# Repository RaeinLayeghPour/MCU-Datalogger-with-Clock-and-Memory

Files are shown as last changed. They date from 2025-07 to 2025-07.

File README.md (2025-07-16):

# MCU Datalogger with Clock and Memory

A microcontroller-based data logging system featuring a real-time clock (RTC) and external memory (EEPROM/SPI flash) to timestamp and store sensor readings for offline retrieval and analysis.

---

## Features

- Real-time timestamping via DS3231 (I²C RTC module)
- Data storage on external EEPROM or SPI flash memory
- Configurable sampling interval and data format
- Power-efficient design for long-term deployment
- Accessible serial interface for data download/monitoring

---

## Tech Stack & Hardware

- **MCU:** Arduino Uno / ATmega328P
- **RTC:** DS3231 module (I²C)
- **Memory:** External EEPROM or SPI flash (e.g., 24LC256, 25LC512)
- **Language:** Arduino C/C++
- **Interface:** Serial (USB) + I²C/SPI protocols

---

## How It Works

1. On boot, the MCU initializes the RTC and memory.
2. Sensor data (analog/digital) is sampled at configured intervals.
3. Each reading is timestamped using the RTC.
4. Records are stored sequentially in external memory.
5. Data can be retrieved via serial commands (e.g., `dump`, `clear`).

---

## Applications

- Remote environmental monitoring (e.g., temperature, humidity)
- Power data logging (voltage/current)
- Industrial sensing (vibration, pressure)
- Educational electronics and embedded systems projects

---

## 📬 Contact

Reach out if you’d like to collaborate or discuss enhancements:

- [LinkedIn](https://www.linkedin.com/in/raeinlp)
- Email: raeen.layegh2017@gmail.com

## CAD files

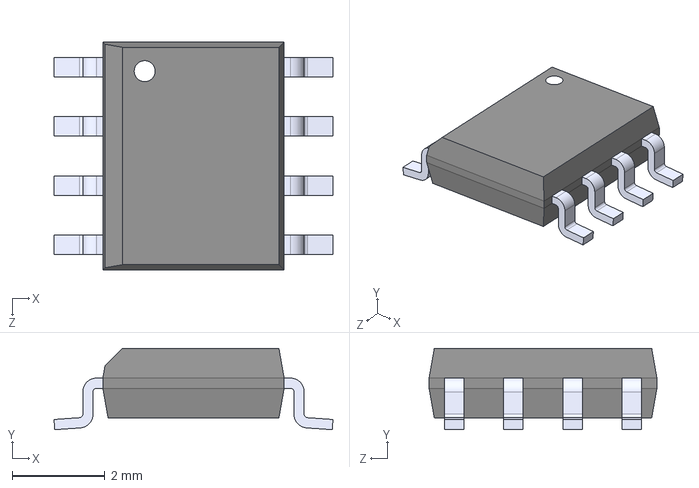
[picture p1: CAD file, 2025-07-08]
DS1337S+.STEP
6.00 x 1.75 x 4.90 mm

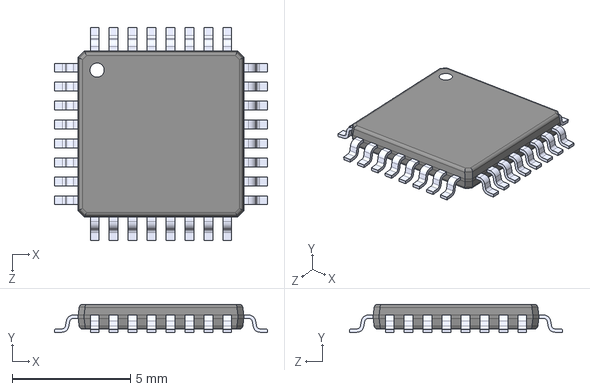
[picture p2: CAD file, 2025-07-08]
ATMEGA328P-AUR.step
9.00 x 1.20 x 9.00 mm

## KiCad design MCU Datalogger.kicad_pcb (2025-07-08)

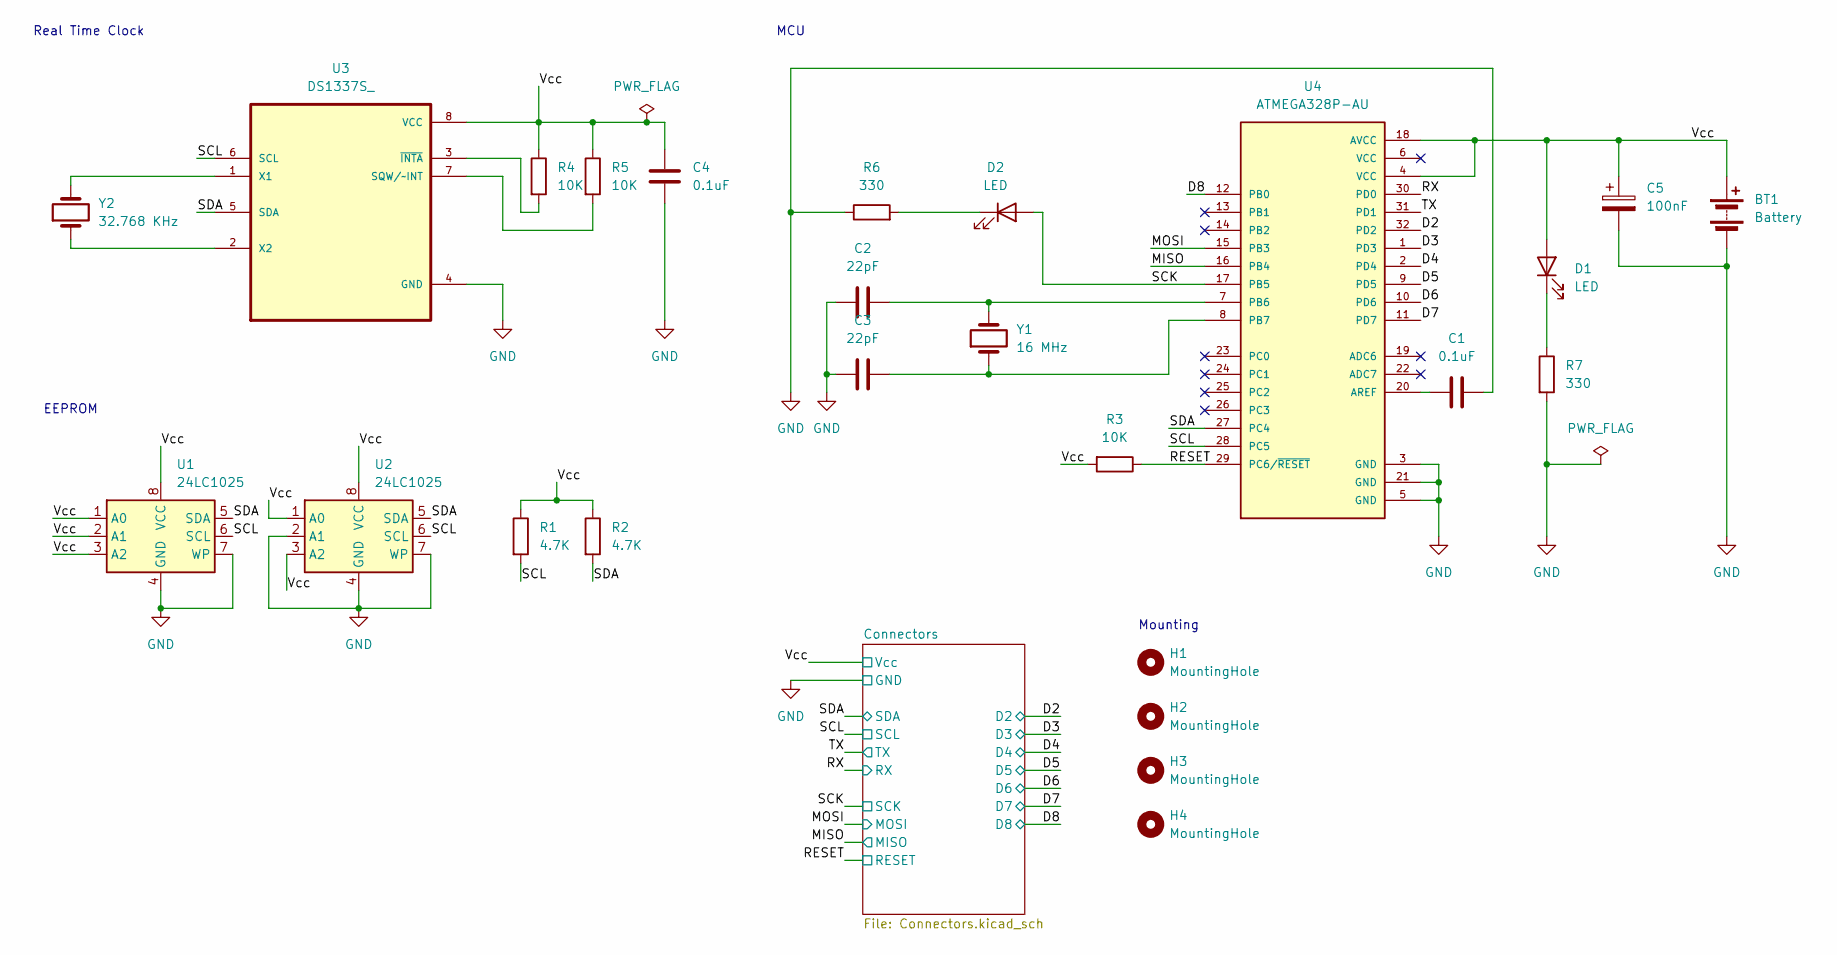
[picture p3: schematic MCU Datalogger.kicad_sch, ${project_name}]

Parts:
BT1: Battery; PinHeader_1x02_P2.54mm_Vertical
C1, C4: 0.1uF; C_0805_2012Metric
C2, C3: 22pF; C_0805_2012Metric
C5: 100nF; C_0805_2012Metric
D1, D2: LED; LED_0805_2012Metric
H1, H2, H3, H4: MountingHole; MountingHole_2.1mm
R1, R2: 4.7K; R_0805_2012Metric
R3, R4, R5: 10K; R_0805_2012Metric
R6, R7: 330; R_0805_2012Metric
U1, U2: 24LC1025; SSOP-8_5.25x5.24mm_P1.27mm
U3: DS1337S_; SOIC127P600X175-8N
U4: ATMEGA328P-AU; QFP80P900X900X120-32N; PARTREV 8271A
Y1: 16 MHz; Crystal_SMD_5032-2Pin_5.0x3.2mm_HandSoldering
Y2: 32.768 KHz; Crystal_SMD_5032-2Pin_5.0x3.2mm_HandSoldering

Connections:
/D2: U4.32 (PD2); also elsewhere on the board
/D3: U4.1 (PD3); also elsewhere on the board
/D4: U4.2 (PD4); also elsewhere on the board
/D5: U4.9 (PD5); also elsewhere on the board
/D6: U4.10 (PD6); also elsewhere on the board
/D7: U4.11 (PD7); also elsewhere on the board
/D8: U4.12 (PB0); also elsewhere on the board
/MISO: U4.16 (PB4); also elsewhere on the board
/MOSI: U4.15 (PB3); also elsewhere on the board
/RESET: R3.1, U4.29 (PC6/~RESET); also elsewhere on the board
/RX: U4.30 (PD0); also elsewhere on the board
/SCK: D2.2 (A), U4.17 (PB5); also elsewhere on the board
/SCL: R1.2, U1.6 (SCL), U2.6 (SCL), U3.6 (SCL), U4.28 (PC5); also elsewhere on the board
/SDA: R2.2, U1.5 (SDA), U2.5 (SDA), U3.5 (SDA), U4.27 (PC4); also elsewhere on the board
/TX: U4.31 (PD1); also elsewhere on the board
/Vcc: BT1.1 (+), C4.1, C5.1, D1.2 (A), R1.1, R2.1, R3.2, R4.1, R5.1, U1.1 (A0), U1.2 (A1), U1.3 (A2), U1.8 (VCC), U2.1 (A0), U2.3 (A2), U2.8 (VCC), U3.8 (VCC), U4.4 (VCC), U4.18 (AVCC); also elsewhere on the board
GND: BT1.2 (-), C1.2, C2.1, C3.1, C4.2, C5.2, R6.1, R7.2, U1.4 (GND), U1.7 (WP), U2.2 (A1), U2.4 (GND), U2.7 (WP), U3.4 (GND), U4.3 (GND), U4.5 (GND), U4.21 (GND); also elsewhere on the board
unnamed: D1.1 (K), R7.1
unnamed: D2.1 (K), R6.2
unnamed: R5.2, U3.7 (SQW/~INT)
unnamed: U3.1 (X1), Y2.2
unnamed: U3.2 (X2), Y2.1
unnamed: R4.2, U3.3 (~INTA)
unnamed: C1.1, U4.20 (AREF)
unnamed: C2.2, U4.7 (PB6), Y1.2
unnamed: C3.2, U4.8 (PB7), Y1.1

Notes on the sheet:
EEPROM
Mounting
MCU
Real Time Clock

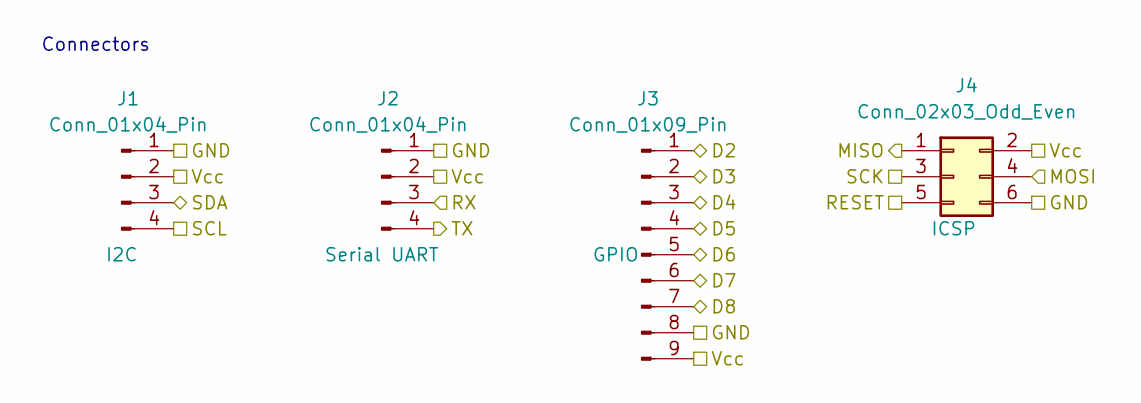
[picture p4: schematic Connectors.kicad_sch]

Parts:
J1, J2: Conn_01x04_Pin; PinHeader_1x04_P2.54mm_Vertical
J3: Conn_01x09_Pin; PinHeader_1x09_P2.54mm_Vertical
J4: Conn_02x03_Odd_Even; PinHeader_2x03_P2.54mm_Vertical

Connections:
/D2: J3.1; also elsewhere on the board
/D3: J3.2; also elsewhere on the board
/D4: J3.3; also elsewhere on the board
/D5: J3.4; also elsewhere on the board
/D6: J3.5; also elsewhere on the board
/D7: J3.6; also elsewhere on the board
/D8: J3.7; also elsewhere on the board
/MISO: J4.1; also elsewhere on the board
/MOSI: J4.4; also elsewhere on the board
/RESET: J4.5; also elsewhere on the board
/RX: J2.3; also elsewhere on the board
/SCK: J4.3; also elsewhere on the board
/SCL: J1.4; also elsewhere on the board
/SDA: J1.3; also elsewhere on the board
/TX: J2.4; also elsewhere on the board
/Vcc: J1.2, J2.2, J3.9, J4.2; also elsewhere on the board
GND: J1.1, J2.1, J3.8, J4.6; also elsewhere on the board

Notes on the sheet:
Connectors

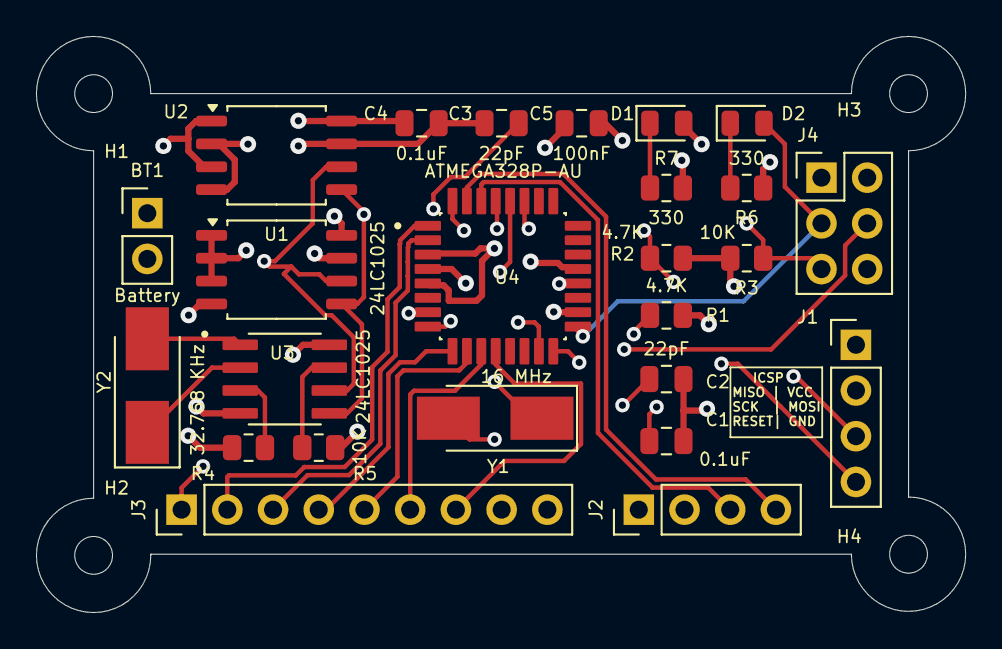
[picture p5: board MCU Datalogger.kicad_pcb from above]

Board: 4 copper layers, 51.6 x 32.0 mm, 29 parts (0 on the bottom side), 26 nets.

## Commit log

2025-07-06 First commit of new project.
    [MCU Datalogger.kicad_pcb, MCU Datalogger.kicad_sch]
2025-07-06 Setup of EEschema for new project.
    [MCU Datalogger.kicad_sch]
2025-07-06 Have added required symbols to the schematic sheets.
    [ATMEGA328P-AU.step, ATMEGA328P-AUR.step, Connectors.kicad_sch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]
2025-07-06 Changed locations of symbols (arrange).
    [MCU Datalogger.kicad_sch]
2025-07-06 Added component values.
    [MCU Datalogger.kicad_sch]
2025-07-07 Completed symbol-footprint associations.
    [Connectors.kicad_sch, MCU Datalogger.kicad_sch]
2025-07-07 Completed wiring of main sheet.
    [MCU Datalogger.kicad_sch]
2025-07-07 Completed wiring in the second sheet.
    [Connectors.kicad_sch, MCU Datalogger.kicad_sch]
2025-07-07 Allocated GND and Vcc nets to the power net class.
2025-07-07 Completed comments.
    [Connectors.kicad_sch, MCU Datalogger.kicad_sch]
2025-07-07 Setup Pcbnew.
    [MCU Datalogger.kicad_pcb, MCU Datalogger.kicad_sch]
2025-07-07 Completed placement of footprints.
    [MCU Datalogger.kicad_pcb]
2025-07-08 Routing sans GND Vcc complete.
    [MCU Datalogger.kicad_pcb]
